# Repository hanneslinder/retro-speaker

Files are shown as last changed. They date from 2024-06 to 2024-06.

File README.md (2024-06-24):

# retro-speaker

A 3d printed bluetooth speaker

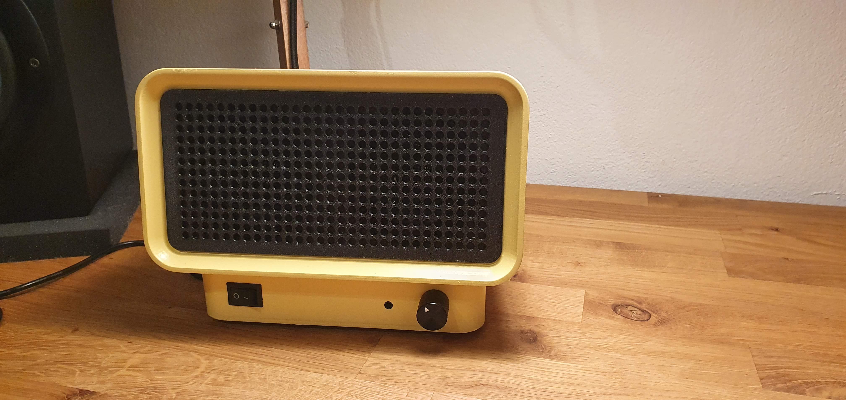
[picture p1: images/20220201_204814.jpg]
The finished speaker


## Materials

The amplifier is a 2x100W TPA3116 board. There are lots of different ones available on Amazon or AliExpress, just make sure the dimensions fit and it has an AUX input in the front. The exact model I've used isn't available on AliExpress any more, but [this one should be a good replacement](https://de.aliexpress.com/item/1005006744130939.html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).

For the speakers I used a pair of [Viston FRS 8 M - 8 Ohm speakers](https://www.visaton.de/de/produkte/chassis/breitband-systeme/frs-8-m-8-ohm).

The power switch is a [KCD1-B1 rocker switch](https://www.hegxing.com.cn/product/rocker-switch-kcd1-b1/), which you can find pretty much anywhere.

In order to connect power I've used [these DC power connectors](https://www.amazon.de/gp/product/B089DXQDS9/ref=ppx_yo_dt_b_search_asin_title?ie=UTF8&psc=1)

The speakers are secured with a bunch of [M3 threaded inserts](https://www.amazon.de/ruthex-Gewindeeinsatz-St%C3%BCck-Gewindebuchsen-Kunststoffteile/dp/B08BCRZZS3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)

The for easy removal the speaker grill is attached with 6 [4x1mm neodym magnets](https://www.amazon.de/Wukong-Magnete-K%C3%BChlschrank-Drucker-DIY-Projekt/dp/B0CH1228D8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) which are glued in place. These magnets hold on to screws on the speaker.

## Print and build

The speaker housing is 3d printed and is split up into 5 separate parts. You can find them in the `/files/stl` directory.

I've printed them with a Prusa mk3s in 0.3mm layer height and PETG. (Some supports might be required for clean printing.)

After printing the `bottom`, `main-housing` and `front` parts need to be glued together. (I've used JBWeld)

M3 threaded inserts need to be inserted into the holes in order to secure the speakers.

I've also sanded, primed and spray painted the housing to give it a niced finish.

Here are a couple of pictures to better show the insides:

The main speaker parts after gluing together and inserting threaded inserts:
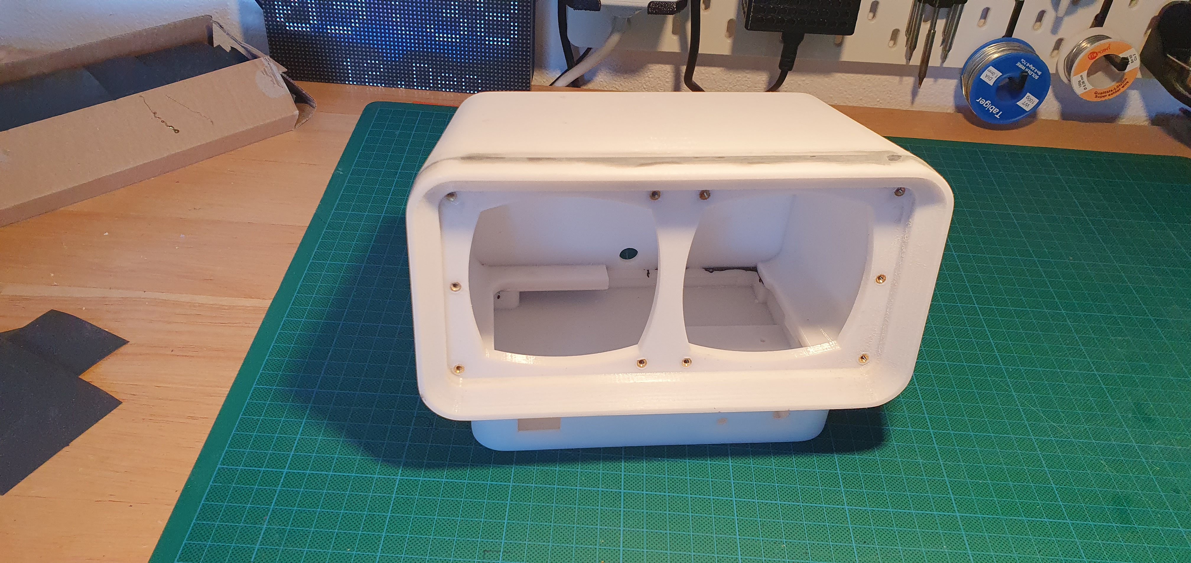
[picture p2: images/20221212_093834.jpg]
The main speaker parts after gluing them together


The housing, speakers and amplifier (and masking tape around the speaker mount):
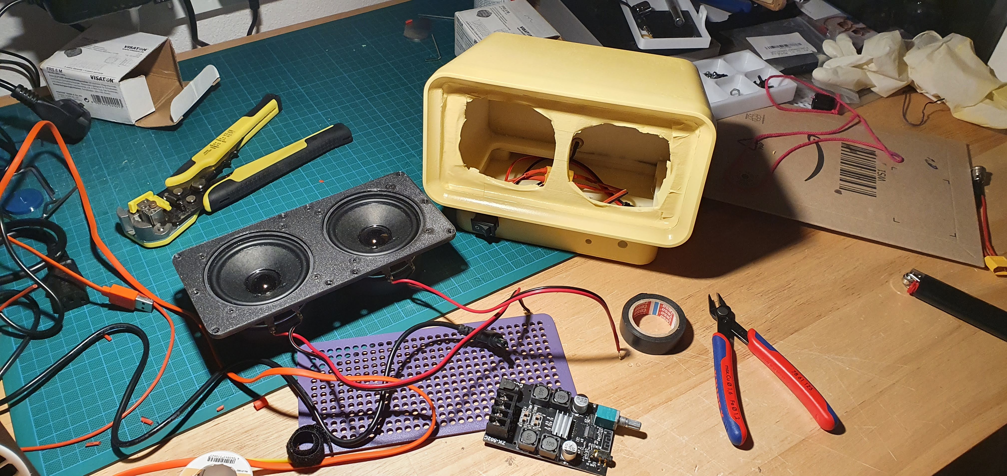
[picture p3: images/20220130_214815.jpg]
The housing, speakers and amplifier


Internal power wiring:
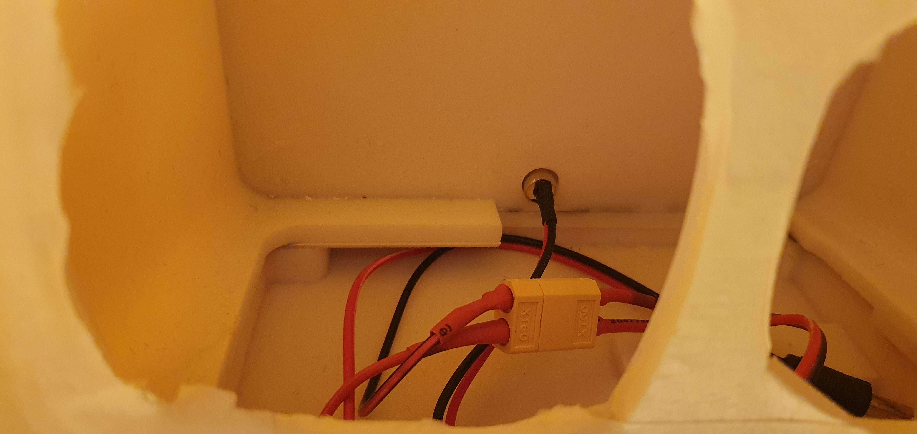
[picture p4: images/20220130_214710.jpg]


Speaker with detached grill:
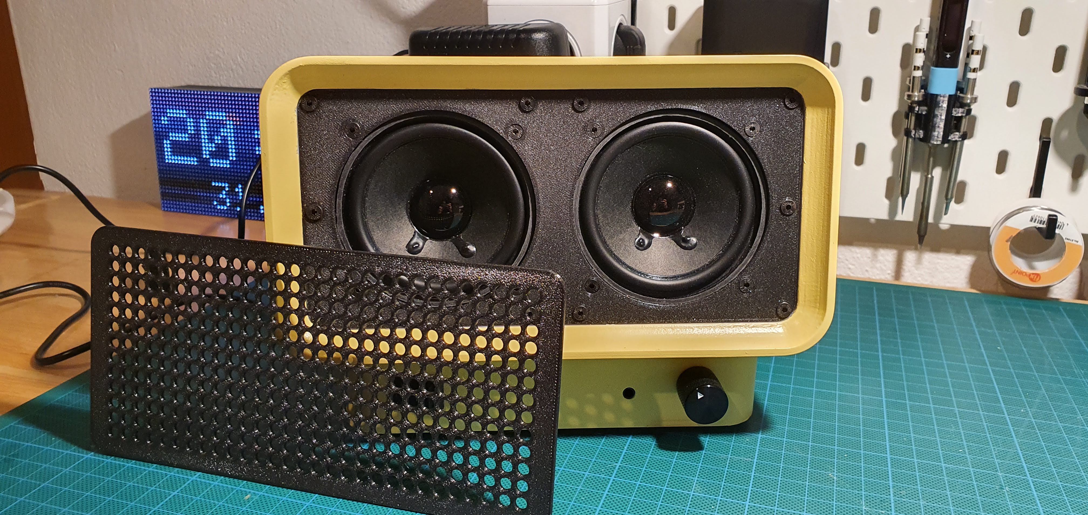
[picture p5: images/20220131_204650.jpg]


Fusion 360 model
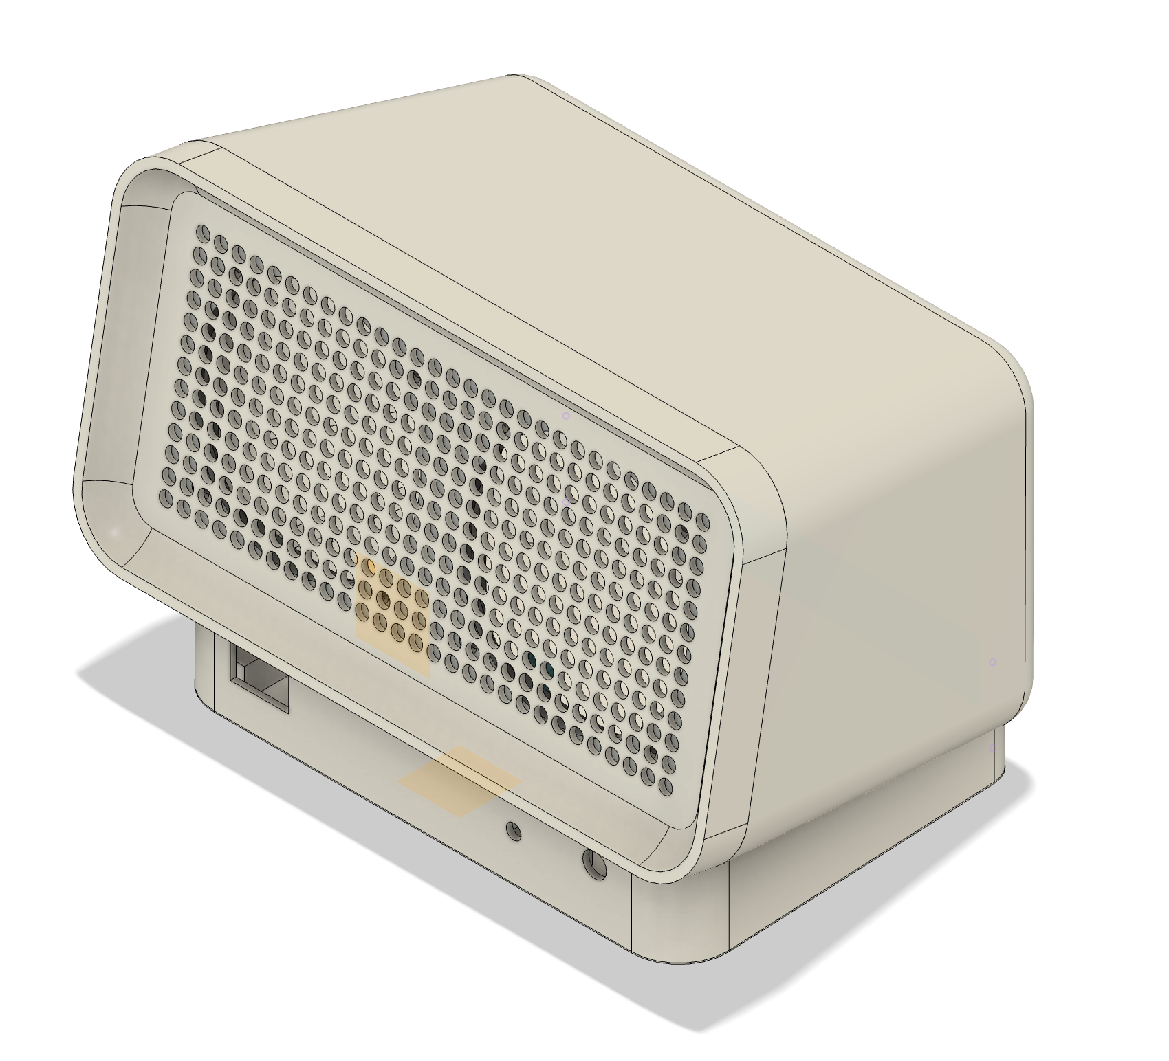
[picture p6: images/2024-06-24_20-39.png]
Fusion 360 model


Mounting holes for 4x1mm neodym magnets
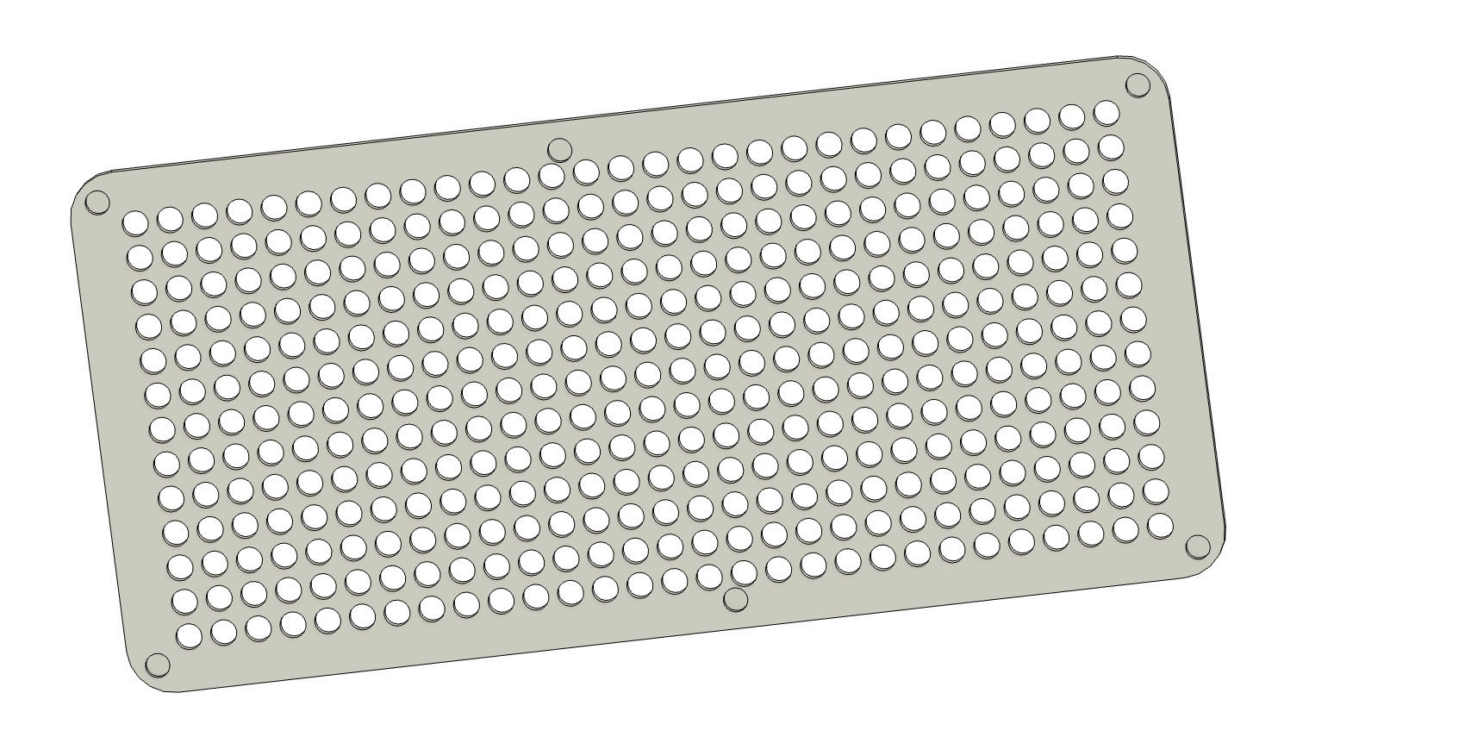
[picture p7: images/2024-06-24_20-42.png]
Mounting holes for 4x1mm neodym magnets


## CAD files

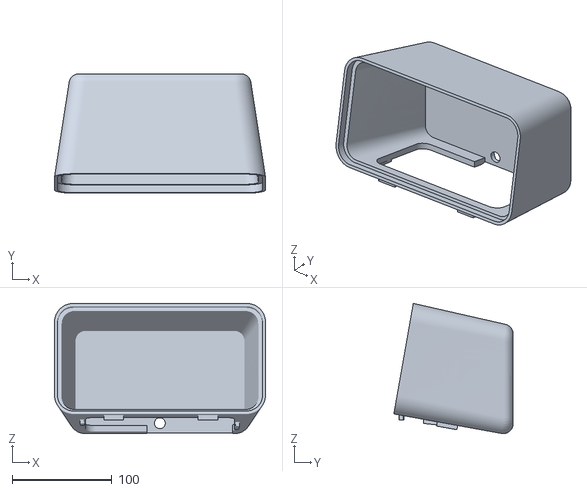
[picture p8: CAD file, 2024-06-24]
files/stl/main-housing.stl
211.9 x 119.9 x 130.8

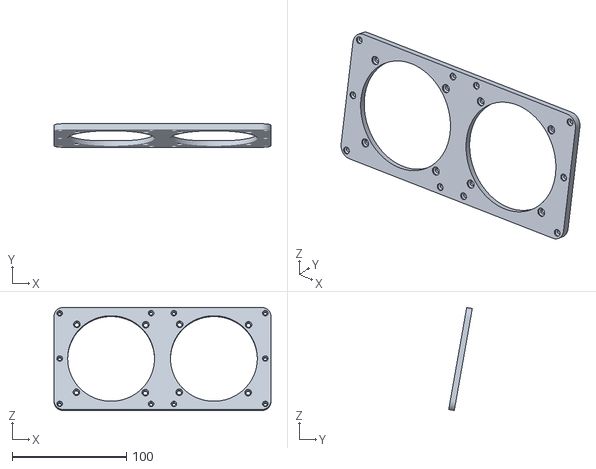
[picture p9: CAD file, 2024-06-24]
files/stl/speaker-holder.stl
189.9 x 20.7 x 90.2

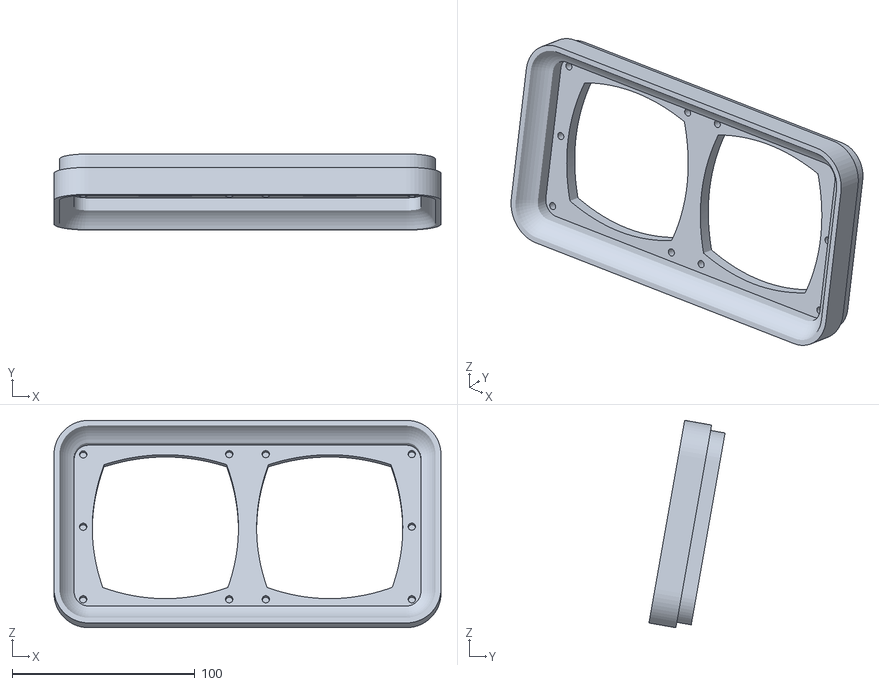
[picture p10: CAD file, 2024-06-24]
files/stl/front.stl
211.9 x 41.7 x 113.6

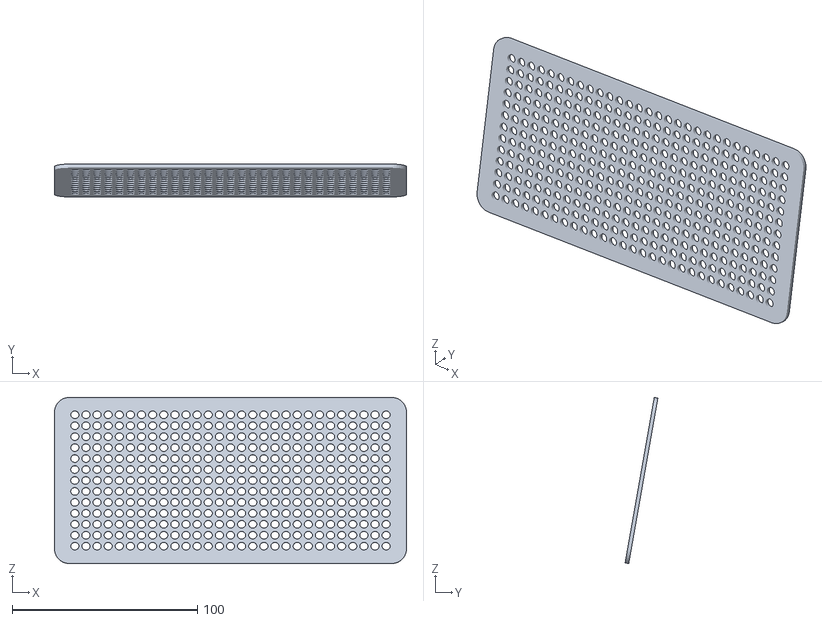
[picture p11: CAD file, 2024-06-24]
files/stl/grill.stl
189.9 x 17.7 x 89.7

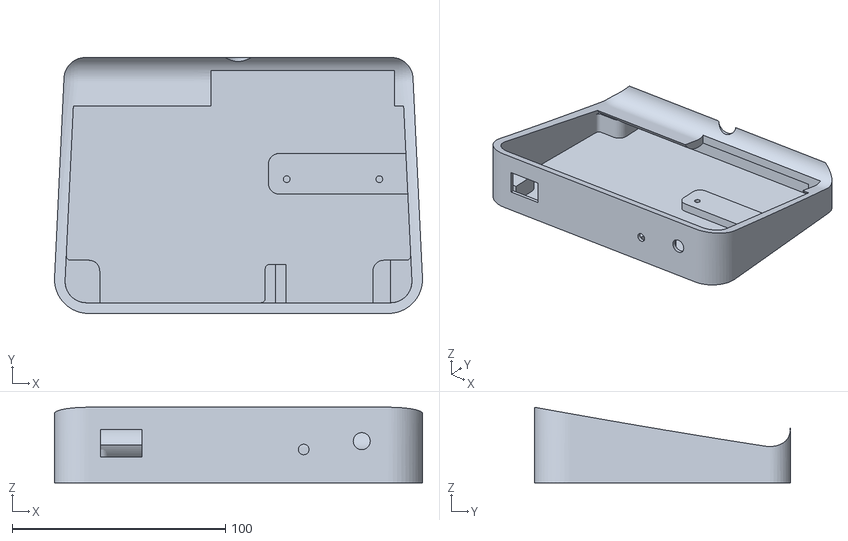
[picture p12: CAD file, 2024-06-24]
files/stl/bottom.stl
172.4 x 119.9 x 35.4

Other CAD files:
files/speaker.f3z

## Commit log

2024-06-24 Add documentation and files
    [bottom.stl, front.stl, grill.stl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]
2024-06-24 show magnet mounting position
